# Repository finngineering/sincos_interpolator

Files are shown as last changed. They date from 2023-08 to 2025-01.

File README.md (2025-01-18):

# SinCos Interpolator
The SinCos Interpolator reads the analog signals from (e.g. Heidenhain) linear scales and converts them into digital quadrature signals. The design is based on the iC-NV chip by iC-Haus. This board performs essentially the same function as Heidenhain "EXE" converters. The design was created for Heidenhain LS 403 linear scales with 11 uA peak-to-peak signals. Through different component values and solder jumper configuration, it should be usable also for other linear scales and similar transducers.

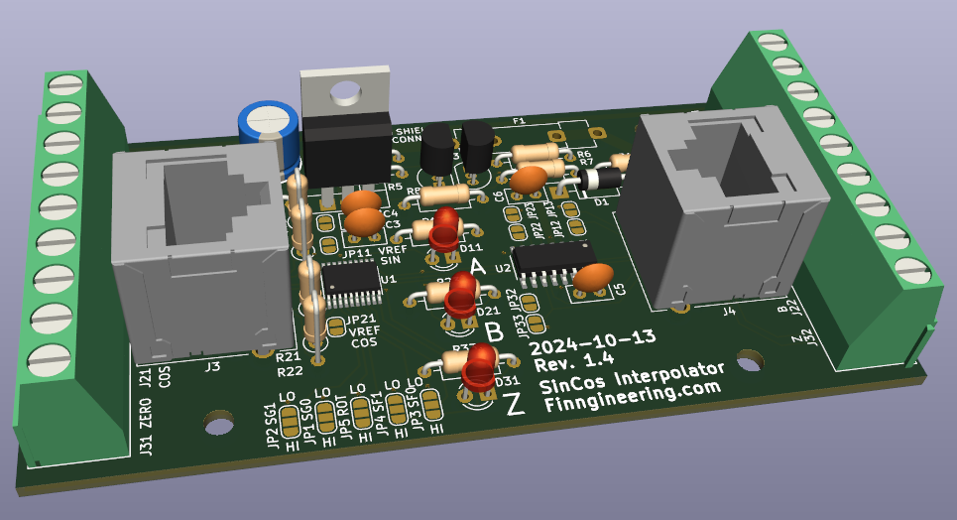
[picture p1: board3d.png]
Board 3d view


## Disclaimer
As of 2025-01-18, the latest version is 1.4 (which has RJ45 jacks rotated 180° compared to version 1.3). This design has been tested to a small extent and is working. However, there appears to be reason to make some accomodations for low pass filtering of the input signals. Version 1.0 tested appeared to be otherwise working, but had power/ground swapped for the MC3487DX IC. A RJ45 jack for the encoder side has also been added since version 1.0.

## Features
- Converts analog sine/cosine signals into digital quadrature outputs
- Interpolation factor selectable by solder jumpers
- Suitable for different type of input signals by resistor selection and solder jumper configuration
- Single ended or differential outputs (the latter with additional MC3487DX IC)
- Support for index/reference signal
- Normal screw terminal blocks with 5.08 mm raster for connections
- Optionally shielded RJ45 connectors for inputs and/or outputs
- Reverse polarity protection
- Overvoltage protection through crowbar circuit
- Using mainly through hole component for ease of soldering
- Two layer board with components on top side only

## Using with 11 uA peak-to-peak transducers (e.g. LS 403)

By component values and solder jumper configuration, the board can be adapted to different type of transducers. For 11 uA peak-to-peak transducers, resistors R11, R12, R21 and R22 should have a 25 kOhm resistance and VREF jumpers JP11 and JP21 should be shorted by soldering. Jumper JP2/SG1 should be soldered "LO" (circuit ground) and JP1/SG0 should be left open to allow signal amplitues of up to 1 Vpp. Jumper JP5/ROT can be soldered "LO" unless some specific phase behaviour is required. Jumpers JP4/SF1 and JP3/SF0 are both left open for an interpolation factor of 5. With the 20 um periodicity of the LS 402 linear scales, this gives an output resolution of 1 um (provided the flanks of the A/B signals are "counted"). Jumper JP6/RCLK should be soldered short unless minimun transition distance needs to be adjusted. For all suggestions given in this paragraph, the iC-NV datasheet is not exceptionally clear, and you may want to do you own interpretation.

Single ended or differential outputs are selected by jumpers JP12-JP13, JP22-JP23 and JP32-JP33. In the open state, differential outputs are used, which also requires the board to be populated with the MC3487DX IC. In case single ended signals are preferred, the MC3487DX is left out and the aforementioned jumpers are soldered short. This connects the output from the iC-NV directly to the "positive" output signal terminals and the "negative" signal terminals are tied to ground.

One of the ground terminals was separated out as shield in version 1.3. This can be connected through (wihtout connecting it to ground) by soldering short JP8. Both input/output ends can also be tied to ground individually through JP7/JP9.

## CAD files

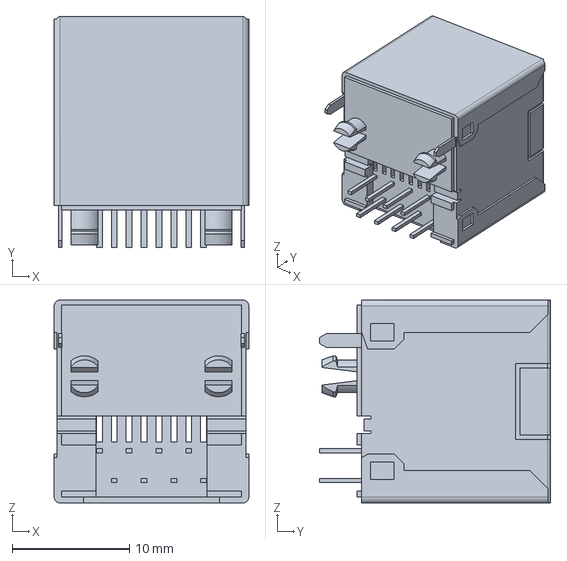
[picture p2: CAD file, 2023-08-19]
hardware/3dmodels/855085001.stp
16.6 x 19.7 x 17.3 mm

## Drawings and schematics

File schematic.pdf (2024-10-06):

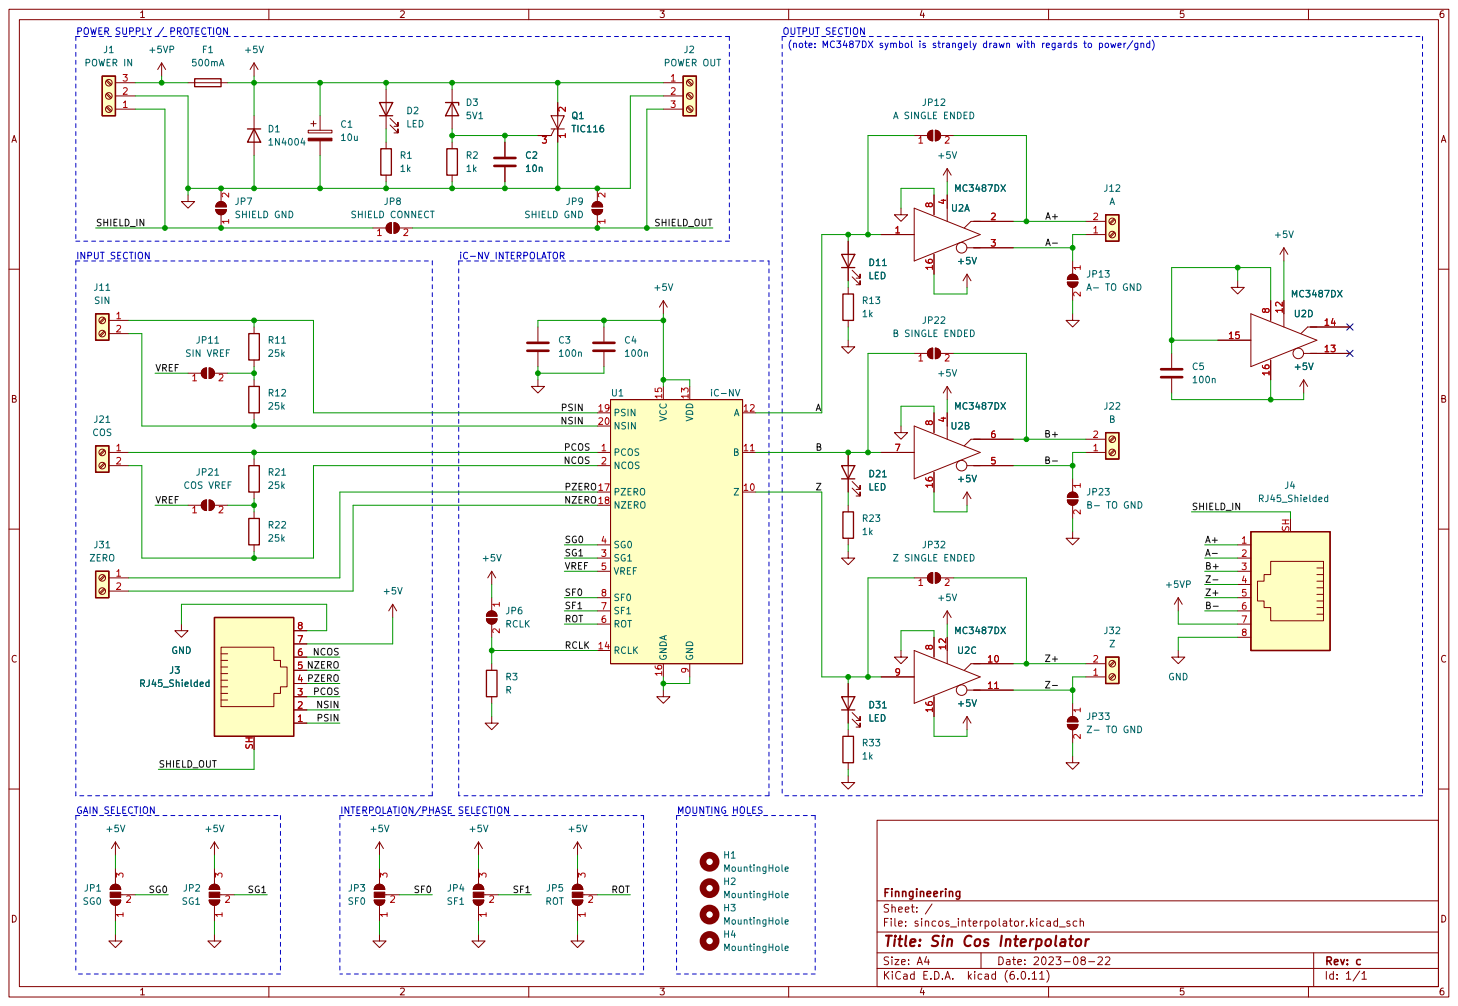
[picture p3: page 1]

NSIN | 11 A | B

PCOS

NZERO

Id: 1/1 Title: Sin Cos Interpolator File: sincos_interpolator.kicad_sch Sheet: / Finngineering

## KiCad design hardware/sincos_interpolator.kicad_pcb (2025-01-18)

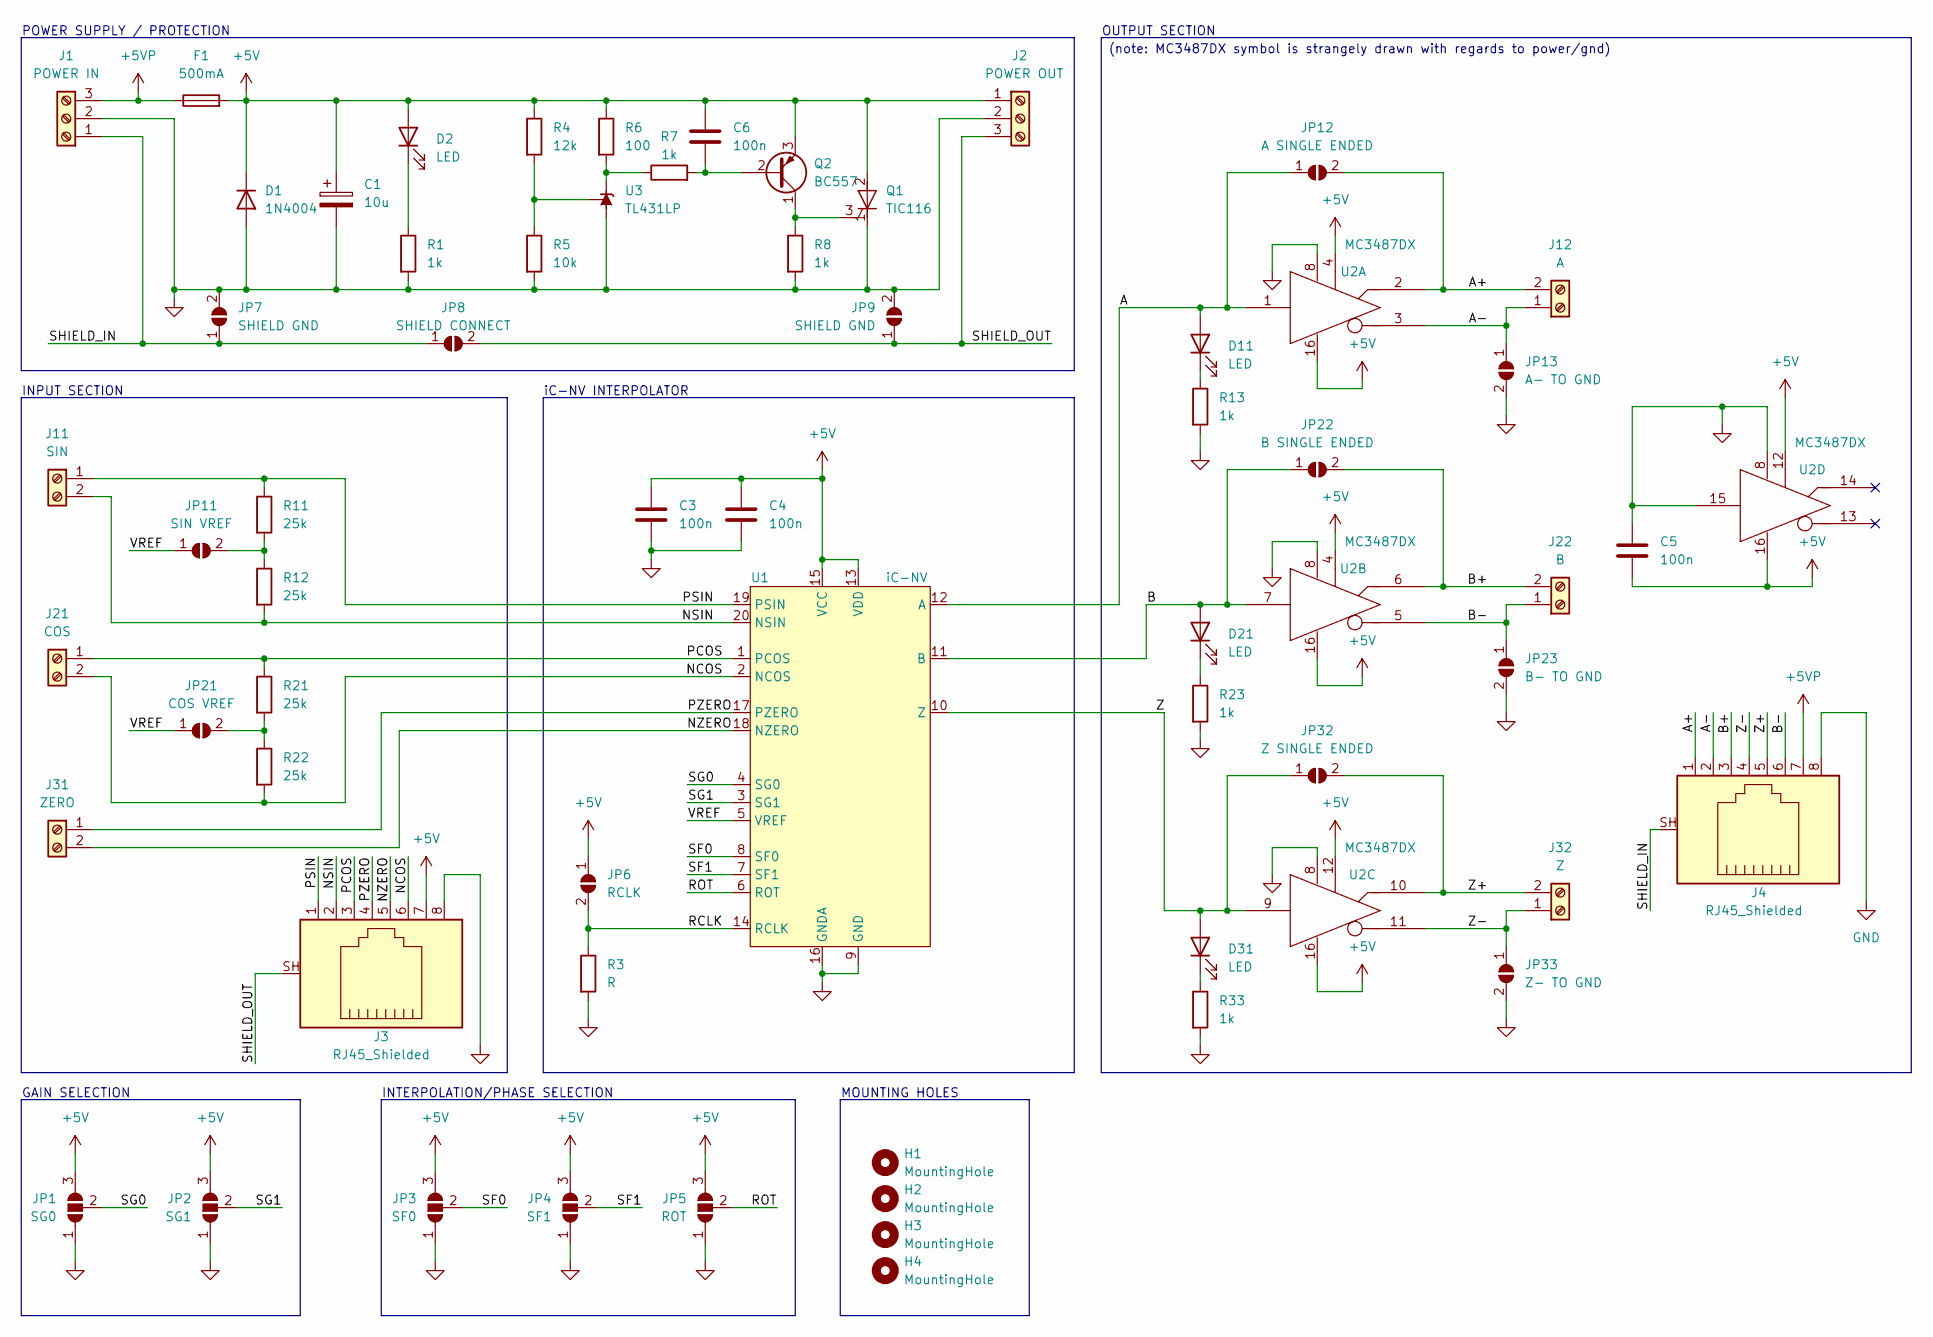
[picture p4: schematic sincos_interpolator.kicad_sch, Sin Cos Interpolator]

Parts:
C1: 10u; CP_Radial_D7.5mm_P2.50mm
C3, C4, C5, C6: 100n; C_Disc_D5.0mm_W2.5mm_P2.50mm
D1: 1N4004; D_DO-41_SOD81_P10.16mm_Horizontal
D2, D11, D21, D31: LED; LED_D3.0mm
F1: 500mA; Fuseholder_Clip-5x20mm_Littelfuse_520_Inline_P20.50x5.80mm_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
H1, H2, H3, H4: MountingHole; MountingHole_3.2mm_M3_ISO14580
J1: POWER IN; TerminalBlock_Phoenix_MKDS-1,5-3-5.08_1x03_P5.08mm_Horizont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
J2: POWER OUT; TerminalBlock_Phoenix_MKDS-1,5-3-5.08_1x03_P5.08mm_Horizont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
J3, J4: RJ45_Shielded; RJ45_Molex_855085001
J11: SIN; TerminalBlock_Phoenix_MKDS-1,5-2-5.08_1x02_P5.08mm_Horizont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
J12: A; TerminalBlock_Phoenix_MKDS-1,5-2-5.08_1x02_P5.08mm_Horizont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
J21: COS; TerminalBlock_Phoenix_MKDS-1,5-2-5.08_1x02_P5.08mm_Horizont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
J22: B; TerminalBlock_Phoenix_MKDS-1,5-2-5.08_1x02_P5.08mm_Horizont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
J31: ZERO; TerminalBlock_Phoenix_MKDS-1,5-2-5.08_1x02_P5.08mm_Horizont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
J32: Z; TerminalBlock_Phoenix_MKDS-1,5-2-5.08_1x02_P5.08mm_Horizont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
JP1: SG0; SolderJumper-3_P1.3mm_Open_RoundedPad1.0x1.5mm
JP2: SG1; SolderJumper-3_P1.3mm_Open_RoundedPad1.0x1.5mm
JP3: SF0; SolderJumper-3_P1.3mm_Open_RoundedPad1.0x1.5mm
JP4: SF1; SolderJumper-3_P1.3mm_Open_RoundedPad1.0x1.5mm
JP5: ROT; SolderJumper-3_P1.3mm_Open_RoundedPad1.0x1.5mm
JP6: RCLK; SolderJumper-2_P1.3mm_Open_RoundedPad1.0x1.5mm
JP7, JP9: SHIELD GND; SolderJumper-2_P1.3mm_Open_RoundedPad1.0x1.5mm
JP8: SHIELD CONNECT; SolderJumper-2_P1.3mm_Open_RoundedPad1.0x1.5mm
JP11: SIN VREF; SolderJumper-2_P1.3mm_Open_RoundedPad1.0x1.5mm
JP12: A SINGLE ENDED; SolderJumper-2_P1.3mm_Open_RoundedPad1.0x1.5mm
JP13: A- TO GND; SolderJumper-2_P1.3mm_Open_RoundedPad1.0x1.5mm
JP21: COS VREF; SolderJumper-2_P1.3mm_Open_RoundedPad1.0x1.5mm
JP22: B SINGLE ENDED; SolderJumper-2_P1.3mm_Open_RoundedPad1.0x1.5mm
JP23: B- TO GND; SolderJumper-2_P1.3mm_Open_RoundedPad1.0x1.5mm
JP32: Z SINGLE ENDED; SolderJumper-2_P1.3mm_Open_RoundedPad1.0x1.5mm
JP33: Z- TO GND; SolderJumper-2_P1.3mm_Open_RoundedPad1.0x1.5mm
Q1: TIC116; TO-220-3_Vertical
Q2: BC557; TO-92_Inline
R1, R7, R8, R13, R23, R33: 1k; R_Axial_DIN0207_L6.3mm_D2.5mm_P10.16mm_Horizontal
R3: R; R_Axial_DIN0207_L6.3mm_D2.5mm_P10.16mm_Horizontal
R4: 12k; R_Axial_DIN0207_L6.3mm_D2.5mm_P10.16mm_Horizontal
R5: 10k; R_Axial_DIN0207_L6.3mm_D2.5mm_P10.16mm_Horizontal
R6: 100; R_Axial_DIN0207_L6.3mm_D2.5mm_P10.16mm_Horizontal
R11, R12, R21, R22: 25k; R_Axial_DIN0207_L6.3mm_D2.5mm_P2.54mm_Vertical
U1: iC-NV; TSSOP-20_4.4x6.5mm_P0.65mm
U2: MC3487DX; SOIC-16_3.9x9.9mm_P1.27mm
U3: TL431LP; TO-92_Inline

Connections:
+5V: C1.1, C3.1, C4.1, C5.2, C6.1, D1.1 (K), D2.2 (A), F1.2, J2.1, J3.7, JP1.3 (B), JP2.3 (B), JP3.3 (B), JP4.3 (B), JP5.3 (B), JP6.1 (A), Q1.2 (A), Q2.3 (E), R4.1, R6.1, U1.13 (VDD), U1.15 (VCC), U2.4 (ENABLE), U2.12 (ENABLE), U2.16 (VCC)
+5VP: F1.1, J1.3, J4.7
/A: D11.2 (A), JP12.1 (A), U1.12 (A), U2.1 (INPUT)
/A+: J4.1, J12.2, JP12.2 (B), U2.2 (OUT+)
/A-: J4.2, J12.1, JP13.1 (A), U2.3 (OUT-)
/B: D21.2 (A), JP22.1 (A), U1.11 (B), U2.7 (INPUT)
/B+: J4.3, J22.2, JP22.2 (B), U2.6 (OUT+)
/B-: J4.6, J22.1, JP23.1 (A), U2.5 (OUT-)
/NCOS: J3.6, J21.2, R22.2, U1.2 (NCOS)
/NSIN: J3.2, J11.2, R12.2, U1.20 (NSIN)
/NZERO: J3.5, J31.2, U1.18 (NZERO)
/PCOS: J3.3, J21.1, R21.1, U1.1 (PCOS)
/PSIN: J3.1, J11.1, R11.1, U1.19 (PSIN)
/PZERO: J3.4, J31.1, U1.17 (PZERO)
/RCLK: JP6.2 (B), R3.1, U1.14 (RCLK)
/ROT: JP5.2 (C), U1.6 (ROT)
/SF0: JP3.2 (C), U1.8 (SF0)
/SF1: JP4.2 (C), U1.7 (SF1)
/SG0: JP1.2 (C), U1.4 (SG0)
/SG1: JP2.2 (C), U1.3 (SG1)
/SHIELD_IN: J1.1, J4.SH, JP7.1 (A), JP8.1 (A)
/SHIELD_OUT: J2.3, J3.SH, JP8.2 (B), JP9.1 (A)
/VREF: JP11.1 (A), JP21.1 (A), U1.5 (VREF)
/Z: D31.2 (A), JP32.1 (A), U1.10 (Z), U2.9 (INPUT)
/Z+: J4.5, J32.2, JP32.2 (B), U2.10 (OUT+)
/Z-: J4.4, J32.1, JP33.1 (A), U2.11 (OUT-)
GND: C1.2, C3.2, C4.2, C5.1, D1.2 (A), J1.2, J2.2, J3.8, J4.8, JP1.1 (A), JP2.1 (A), JP3.1 (A), JP4.1 (A), JP5.1 (A), JP7.2 (B), JP9.2 (B), JP13.2 (B), JP23.2 (B), JP33.2 (B), Q1.1 (K), R1.2, R3.2, R5.2, R8.2, R13.2, R23.2, R33.2, U1.9 (GND), U1.16 (GNDA), U2.8 (GND), U2.15 (INPUT), U3.2 (A)
unnamed: C6.2, Q2.2 (B), R7.2
unnamed: D2.1 (K), R1.1
unnamed: D11.1 (K), R13.1
unnamed: D21.1 (K), R23.1
unnamed: D31.1 (K), R33.1
unnamed: JP11.2 (B), R11.2, R12.1
unnamed: JP21.2 (B), R21.2, R22.1
unnamed: Q1.3 (G), Q2.1 (C), R8.1
unnamed: R4.2, R5.1, U3.1 (REF)
unnamed: R6.2, R7.1, U3.3 (K)

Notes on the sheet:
POWER SUPPLY / PROTECTION
OUTPUT SECTION
INPUT SECTION
MOUNTING HOLES
iC-NV INTERPOLATOR
(note: MC3487DX symbol is strangely drawn with regards to power/gnd)
GAIN SELECTION
INTERPOLATION/PHASE SELECTION

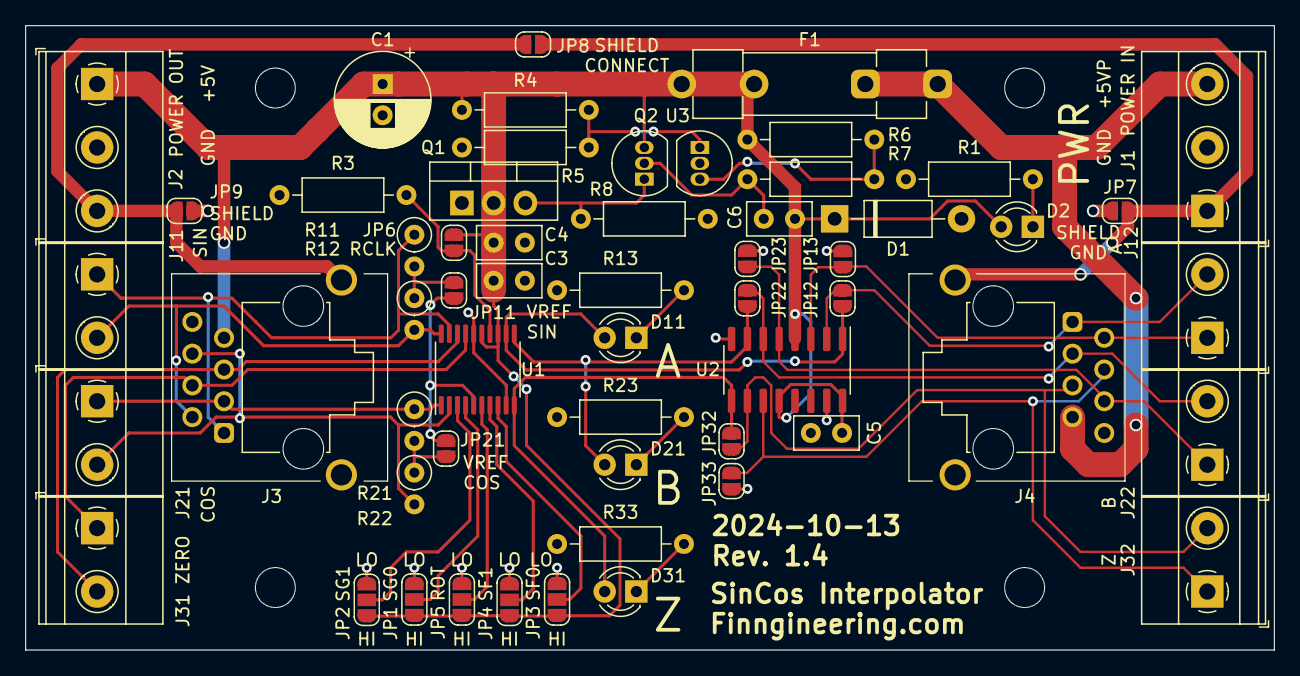
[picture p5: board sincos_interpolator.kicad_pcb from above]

Board: 2 copper layers, 100.0 x 50.0 mm, 61 parts (0 on the bottom side), 37 nets.

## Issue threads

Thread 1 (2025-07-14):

Is it possible to buy few units?

paulsvc, 2025-07-14:
Hello,

Do you sell full board?

Thank you and have a good day

finngineering, 2025-07-15:
No, I don't sell any units. I could send a few unpopulated PCB:s for the shipping cost, but I don't have components (mainly iC-NV) to populate the boards.

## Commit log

2023-08-19 Hardware version 1.1
    [855085001.stp, sincos_interpolator.kicad_pcb, sincos_interpolator.kicad_sch]
2023-08-19 Added board render to the description
2023-08-19 Added schematic as pdf
2023-08-20 New component references and fab outputs
    [sincos_interpolator-B_Cu.gbl, sincos_interpolator-B_Mask.gbs, sincos_interpolator-B_Paste.gbp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]
2023-08-22 Corrected MC3487DX power polarity and separated shield
    [sincos_interpolator-B_Cu.gbl, sincos_interpolator-B_Mask.gbs, sincos_interpolator-B_Paste.gbp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]
2024-10-06 Exported schematic for version 1.3
2025-01-18 RJ45 jacks rotated 180 degrees
    RJ45 jacks rotated 180 degrees to allow the used of angled RJ45 jacks
    [sincos_interpolator-B_Cu.gbl, sincos_interpolator-B_Mask.gbs, sincos_interpolator-B_Paste.gbp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]
2025-01-18 Updated board 3d view to match current design
2025-05-22 Updated pdf schematic to match version 1.4
